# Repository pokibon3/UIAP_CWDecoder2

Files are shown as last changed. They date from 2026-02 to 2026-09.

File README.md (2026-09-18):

# CW Decoder for UIAPduino２

UIAPduino Pro Micro で動作する CW Decoder / FFT Analyzer です。  
VS Code + PlatformIO + `ch32v003fun` ベースでビルドできます。

このリポジトリでは、以下の 2 つのモードを切り替えて使えます。

- CW デコーダ
- FFT スペクトラムアナライザ

MODE SW を押すことでモード切り替えができます。

## 対応 MCU

- CH32V003(UIAPduino Pro Micro CH32V003 V1.4)
- CH32V006(UIAPduino Pro Micro CH32V006 V1.1)

`v1.7` 時点で、CH32V006 向けに以下を反映しています。

- LCD / GPIO 配線差分対応
- FLASH wait state 設定修正
- ADC 入力 `PA2 = ADC_IN0` 修正
- LED 制御を `PC3` に修正
- `ST7735` 向け `12x16` ANK フォント追加
- `ST7789` 向け `15x21` ANK フォント追加
- 006 では拡大描画ではなくネイティブ字形を使用

## 機能

### CW デコーダ

モールス信号を MIC 入力し、デコード結果を LCD に表示します。

- SW1: 英文 / 和文切り替え
- SW2: 600Hz / 700Hz / 800Hz / 900Hz / 1000Hz 切り替え（起動時 600Hz）

### FFT アナライザ

約 2.5kHz までのオーディオ信号スペクトルを表示します。  
ピーク周波数も表示します。

## ハード接続

### CH32V003 / CH32V006

| UIAP | CH32V003 / CH32V006 | 用途 |
|---|---|---|
| 10 | PD0 / PC0 | LCD DC |
| 8 | PC6 | LCD MOSI |
| 9 | PC7 | LCD RES |
| 7 | PC5 | LCD SCK |
| 5 | PC3 / PA4 | LCD CS |
| A1 | PA1 | SW1 |
| A2 | PC4 | SW2 |
| A3 | PD2 | SW3 |
| A0 | PA2 | MIC / ADC_IN0 |
| A6 | PD6 | TEST |
| LED | PC0 / PC3 | LED |

## ビルド

VS Code でこのフォルダを開き、PlatformIO IDE の機能を使ってビルドします。

1. VS Code でこのプロジェクトを開く
2. PlatformIO IDE が有効になっていることを確認する
3. 画面下部の PlatformIO ツールバーから `Build` を実行する

既定の environment は現在 `genericCH32V006F8U6` です。

## ファームウェア更新ツール

更新用パッケージは MCU と LCD 種別ごとに `tools` 配下へ整理しています。

- CH32V003 / ST7735: [tools/003/ST7735](tools/003/ST7735)
- CH32V003 / ST7789: [tools/003/ST7789](tools/003/ST7789)
- CH32V006 / ST7735: [tools/006/ST7735](tools/006/ST7735)
- CH32V006 / ST7789: [tools/006/ST7789](tools/006/ST7789)

今回の `v2.1` はデコード周波数の5段切り替え（600〜1000Hz）と、ノイズ混じり信号のデコード改善を行った版です。

- CH32V003 / ST7735 `v2.1` macOS: [tools/003/ST7735/mac/firmwareUpdate2.1](tools/003/ST7735/mac/firmwareUpdate2.1)
- CH32V003 / ST7735 `v2.1` Windows: [tools/003/ST7735/win/firmwareUpdate2.1](tools/003/ST7735/win/firmwareUpdate2.1)
- CH32V003 / ST7789 `v2.1` macOS: [tools/003/ST7789/mac/firmwareUpdate2.1](tools/003/ST7789/mac/firmwareUpdate2.1)
- CH32V003 / ST7789 `v2.1` Windows: [tools/003/ST7789/win/firmwareUpdate2.1](tools/003/ST7789/win/firmwareUpdate2.1)
- CH32V006 / ST7735 `v2.1` macOS: [tools/006/ST7735/mac/firmwareUpdate2.1](tools/006/ST7735/mac/firmwareUpdate2.1)
- CH32V006 / ST7735 `v2.1` Windows: [tools/006/ST7735/win/firmwareUpdate2.1](tools/006/ST7735/win/firmwareUpdate2.1)
- CH32V006 / ST7789 `v2.1` macOS: [tools/006/ST7789/mac/firmwareUpdate2.1](tools/006/ST7789/mac/firmwareUpdate2.1)
- CH32V006 / ST7789 `v2.1` Windows: [tools/006/ST7789/win/firmwareUpdate2.1](tools/006/ST7789/win/firmwareUpdate2.1)

`v2.0` 以前のパッケージも各ディレクトリの `firmwareUpdate2.0` などに残しています。

## 変更履歴

- V1.0
  - 新規リリース
- V1.1
  - オーディオ入力のダイナミックレンジ拡大
  - 欧文 / 和文切換えのバグ修正
  - モールスデコーダのデフォルト周波数を 600Hz に変更
  - FFT アナライザのスプラッシュ表示削除
- V1.2
  - DFT 周波数調整
  - 入力オーディオレベル調整
  - 周波数表示を 600Hz から 700Hz に変更
- V1.3
  - デコードタイミング微調整
  - デコード方式改善
- V1.4
  - 音声サンプリングのダブルバッファ化と表示期間の最適化
  - ノイズブランカの改善
  - LCD に 1.14inch ST7735/ST7789 をサポート
- V1.5
  - ST7735 / ST7789 ドライバを新規作成し最適化
  - 速度検出の安定化
  - ノイズによる誤動作の軽減
- V1.6
  - CH32V006 対応
  - GPIO / LCD 配線差分対応
  - FLASH wait state 設定修正
  - ADC 入力 `PA2 = ADC_IN0` 修正
  - ファームウェア更新ツールを `tools` 配下へ整理
- V1.7
  - CH32V006 の表示フォントを改善
  - ST7735 向け `12x16` ANK フォントを追加
  - ST7789 向け `15x21` ANK フォントを追加
  - 006 では拡大描画ではなくネイティブ字形を使用
  - 未認識符号を `*` で表示してバッファをリセットするよう修正
  - 符号バッファのオーバーフロー防止処理を追加
- V1.8
  - Goertzel を3ビン化（中心 + ±341.33Hz サイドビン、1パス処理。003 は整数 Q14、006 は float）
  - 中心/サイド比によるトーン判定を追加し、ホワイトノイズによる誤検出を抑制
  - サイドレベルは平滑化(EMA)後の min(low, high) を使用（片側混信に耐性）
  - 無信号からの立ち上がり時は瞬時サイドレベルも併用し、インパルス性ノイズ（QRN等）の誤検出を阻止
  - 速度推定を改良：長点も推定に利用して収束を高速化、低速側への変化率を制限してノイズバーストによる速度落ち込みを防止、WPM 表示は単位長から直接算出
  - 短点+長点ペア（比率1:3）検出による即時スナップを追加。20〜35wpm 帯ならノイズで倒れた速度推定がペア1組で瞬時に復帰（帯域外は緩やかに追従）
- V1.9
  - トーン判定にヒステリシス（シュミットトリガ）を導入。ON = 0.6×振幅しきい値かつ中心/サイド比3倍、OFF = 0.4×または2.5倍、中間は前状態保持。SNR 0dB でのデコード誤り 30〜43個/40秒 → 1〜2個（シミュレーション）
  - ギャップ（文字内1単位・文字間3単位）も速度推定の情報源に追加し、マーク+ギャップの1:3ペアでもスナップ。速度変化への追従を約2倍高速化（0.5〜0.7秒 → 0.1〜0.3秒）
- V2.0
  - サイド判定を min(low, high) から幾何平均 √(low×high) に変更。低域から通過帯域へ裾を引く傾斜ノイズ（バンドノイズ）が、静かな側のサイドとの比較をすり抜けて偽符号になる問題を抑止（ESP32 版 cw_decoder4 v2.0 で実機検証済みの対策を移植。003 整数版 / 006 float 版とも対応）
  - トーンON条件に「中心 > max(サイドEMA, サイド瞬時値)」を追加
- V2.1
  - デコード周波数を 600 / 700 / 800 / 900 / 1000Hz の5段切り替えに変更（SW2、起動時は 600Hz）
  - 従来 700 / 800Hz と表示していた設定は実際には 666.7 / 833.3Hz だったため、表示どおりの周波数に修正
  - ノイズ混じりの信号を音量を絞らずにデコードできるよう、振幅しきい値の床をノイズ床連動（×6）に変更し入力レベル非依存化。しきい値の追従は立ち上がり速く（1/6）、下降は遅く（1/64）
  - ノイズブランカを上下カウンタの積分方式に変更（深さ 0.35 単位、2〜3 ブロック）。しきい値付近のバタつきでギャップが埋まり短点が長点に融合する誤りを抑止（ESP32 版 cw_decoder4 v2.1/v2.2 の対策を移植）
  - スペアナ画面でスタックが溢れて FFT バッファを壊し、画面が出なくなることがある問題を修正

## 参考

製作方法や使い方は、以下も参照してください。  
[R16 Friendship Radio Scrapbox](https://scrapbox.io/r16fr/UIAPduino%E3%82%92%E4%BD%BF%E3%81%A3%E3%81%9FCW_Decoder%E3%81%AE%E8%A3%BD%E4%BD%9C)

## ライセンス

本ソフトのモールスデコーダ部分は、Hjalmar Skovholm Hansen OZ1JHM 氏の Arduino 用 CW Decoder を一部流用しています。  
オリジナルの GPL ライセンス条件が適用されます。

- Original: [http://oz1jhm.dk/content/very-simpel-cw-decoder-easy-build](http://oz1jhm.dk/content/very-simpel-cw-decoder-easy-build)
- GPL: [http://www.gnu.org/copyleft/gpl.html](http://www.gnu.org/copyleft/gpl.html)

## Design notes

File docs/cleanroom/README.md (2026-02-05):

# Clean-Room ST7789 Driver Plan

This folder defines the clean-room process and captures only specification-level
information. Do not place or copy any third-party source code here.

## Rules
- Do not read or reference existing ST7789 driver source code.
- Only use primary documents (datasheet, MCU reference, wiring).
- Record every assumption with a citation to a primary document.
- Keep implementation decisions separate from the spec.

## Files
- st7789_spec.md: Panel/MCU wiring, geometry, rotation, offsets, color order.
- st7789_init.csv: Initialization command list (sequence + delays).
- st7789_tests.md: Test plan for verification on hardware.

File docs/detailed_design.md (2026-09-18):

# CW Decoder for UIAP 詳細設計書（簡易版）

## 1. 概要
- 本ソフトは CH32V003 上で動作する CW 受信アプリ。
- 2つの動作モードを持つ。
  - CW Decoder Mode: モールス復号
  - Frequency Detector Mode: FFTによる周波数表示
- `SW1` で2モードを切り替える。

## 2. 全体構成
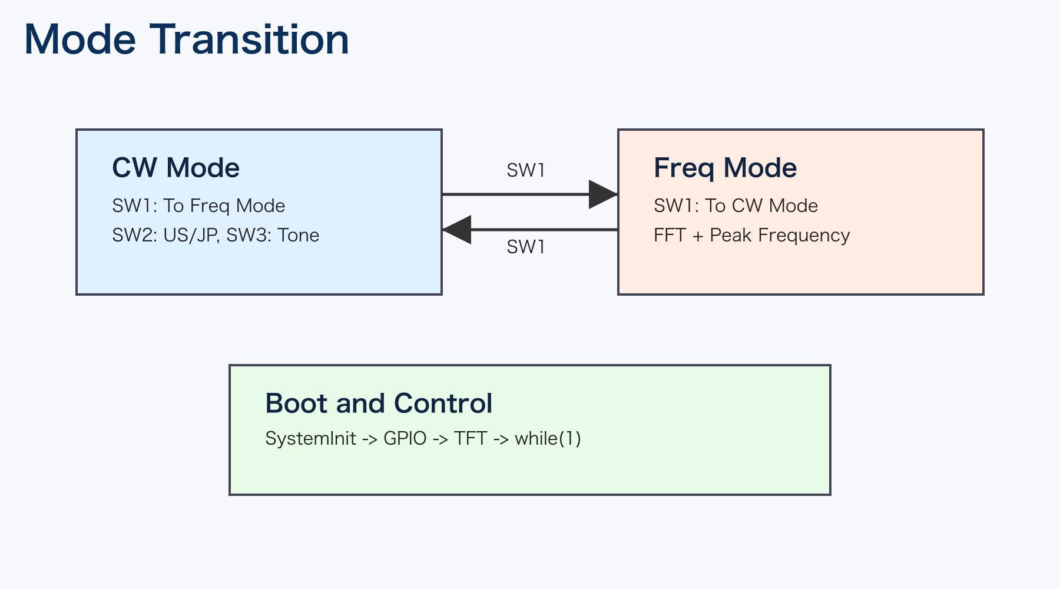
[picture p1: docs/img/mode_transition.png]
Mode Transition


構成要点:
- `main.cpp` がモード切替の主制御を行う。
- `common.cpp` が GPIO/ADC/タイマ/スイッチの共通処理を提供する。
- CW復号は Goertzel、周波数表示は FFT を使用する。
- 表示は TFT 抽象API経由で ST7735/ST7789 を切替可能。

## 3. モード遷移
- 起動後に初期化を行い、無限ループでモードを順に実行。
- CWモード中に `SW1` 押下で FFTモードへ。
- FFTモード中に `SW1` 押下で CWモードへ。

## 4. CW Decoder Mode
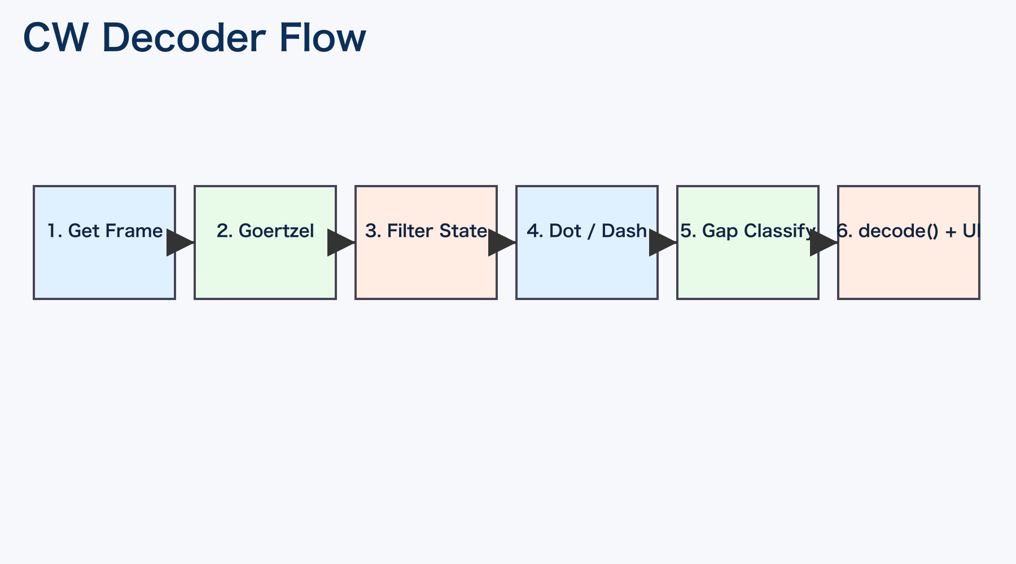
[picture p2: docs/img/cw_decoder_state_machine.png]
CW Decoder Flow


処理の流れ:
1. 音声サンプル取得
2. Goertzelで対象トーン成分を算出
3. しきい値とノイズ抑制でON/OFF状態を決定
4. ON時間から dot/dash 判定
5. OFF時間から文字間/単語間を判定
6. `decode.cpp` テーブルで文字変換し画面へ出力

操作:
- `SW2`: US/JP 切替
- `SW3`: トーン設定切替
- `SW1`: モード終了

## 5. Frequency Detector Mode
- ADCで 128 サンプル取得し FFT 実行。
- 最大ビンからピーク周波数を表示。
- スペクトラムバーを TFT に描画。
- `SW1` 押下でモード終了。

## 6. データとI/O
- 共有バッファ: `shared_buf[256]` を CW/FFT で共用。
- 主な入力:
  - 音声入力: PA2 (ADC)
  - SW1/2/3: PA1/PC4/PD2
- 主な出力:
  - TFT表示
  - LED表示 (CW状態)

## 7. ビルド設定
- `platformio.ini` でターゲットを管理。
- 既定は `TFT_ST7789`。
- 必要に応じて `TFT_ST7735` に切替可能。

## 8. 注意点
- グローバル変数を多用する構成のため、モジュールの独立性は高くない。
- タイミングは実機調整値に依存するため、クロック条件変更時は再調整が必要。

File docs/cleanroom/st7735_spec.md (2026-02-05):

# ST7735 Clean-Room Specification

## Source Documents
- ST7735 datasheet: [fill path or URL]
- CH32V003 reference: D:\src\cw_decoder3_for_uiap\docs\cleanroom\CH32V003.pdf
- Board wiring diagram: [fill path or URL]

## Target Hardware
- MCU: CH32V003
- Panel: ST7735, 80x160
- Interface: SPI 1-line TX
- Color format: 16-bit RGB565 (BGR order)
- Inversion: OFF

## Wiring (MCU -> ST7735)
- RESET: PC7
- DC: PD0
- CS: PC3 (optional if tied low)
- SCLK: PC5
- MOSI: PC6

## Geometry
- Display width: 160 px (landscape)
- Display height: 80 px (landscape)
- X offset: 0
- Y offset: 24

## Orientation
- Rotation: 0 degrees (landscape)
- MADCTL bits: MX=1, MY=0, MV=1, BGR=1
- MADCTL value: 0x68
- Rationale: [cite datasheet]

## Timing
- Reset pulse high/low: [ms]
- Sleep out delay: 120 ms
- Display on delay: 10 ms

## Command Set (minimum)
- SWRESET (0x01)
- SLPOUT (0x11)
- COLMOD (0x3A) = 0x05 (RGB565)
- MADCTL (0x36) = [bits above]
- INVOFF (0x20)
- DISPON (0x29)
- CASET (0x2A), RASET (0x2B), RAMWR (0x2C)
- VSCRDEF (0x33), VSCRSADD (0x37) [if scroll is required]

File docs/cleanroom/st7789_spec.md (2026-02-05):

# ST7789 Clean-Room Specification

## Source Documents
- ST7789 datasheet: D:\src\cw_decoder3_for_uiap\docs\cleanroom\ST7789.pdf
- CH32V003 reference: D:\src\cw_decoder3_for_uiap\docs\cleanroom\CH32V003.pdf
- Board wiring diagram: [fill path or URL]

## Target Hardware
- MCU: CH32V003
- Panel: ST7789, 1.14" 135x240
- Interface: SPI 1-line TX
- Color format: 16-bit RGB565
- Inversion: ON

## Wiring (MCU -> ST7789)
- RESET: PC7
- DC: PD0
- CS: PC3 (optional if tied low)
- SCLK: PC5
- MOSI: PC6

## Geometry
- Display width: 240 px (landscape)
- Display height: 135 px (landscape)
- X offset: 40
- Y offset: 53

## Orientation
- Rotation: 0 degrees
- MADCTL bits: MX=1, MY=0, MV=1, RGB=1, BGR=0
- MADCTL value: 0x60
- Rationale: [cite datasheet]

## Timing
- Reset pulse high/low: [ms]
- Sleep out delay: 120 ms
- Display on delay: 10 ms

## Command Set (minimum)
- SLPOUT (0x11)
- COLMOD (0x3A) = 0x55 (RGB565)
- MADCTL (0x36) = [bits above]
- INVON (0x21)
- DISPON (0x29)
- CASET (0x2A), RASET (0x2B), RAMWR (0x2C)
- VSCRDEF (0x33), VSCRSADD (0x37) [if scroll is required]

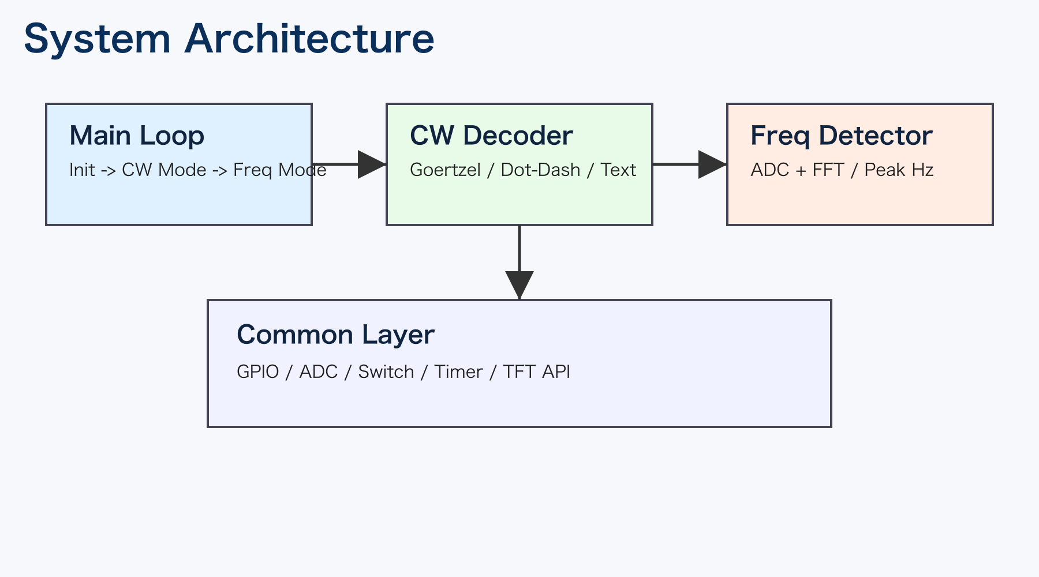
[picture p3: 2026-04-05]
docs/img/system_architecture.png

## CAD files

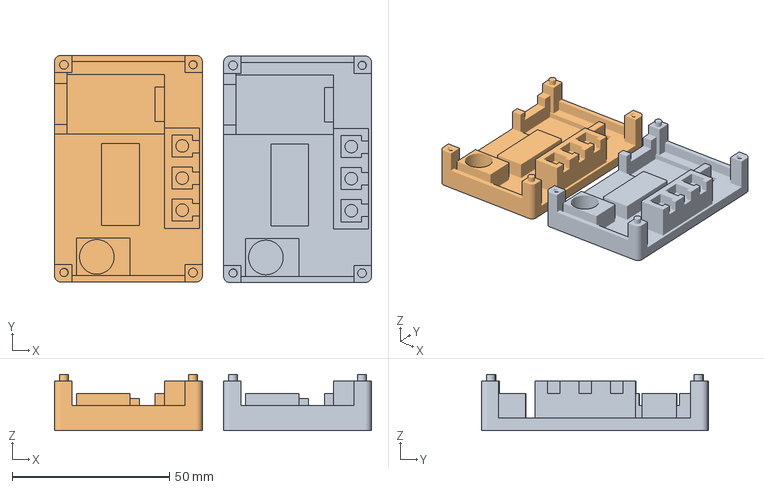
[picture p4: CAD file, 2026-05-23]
case/CW_DecoderSolderBase.3mf
100.7 x 72.2 x 17.8 mm
SOLDER_BASE2.stl x 2

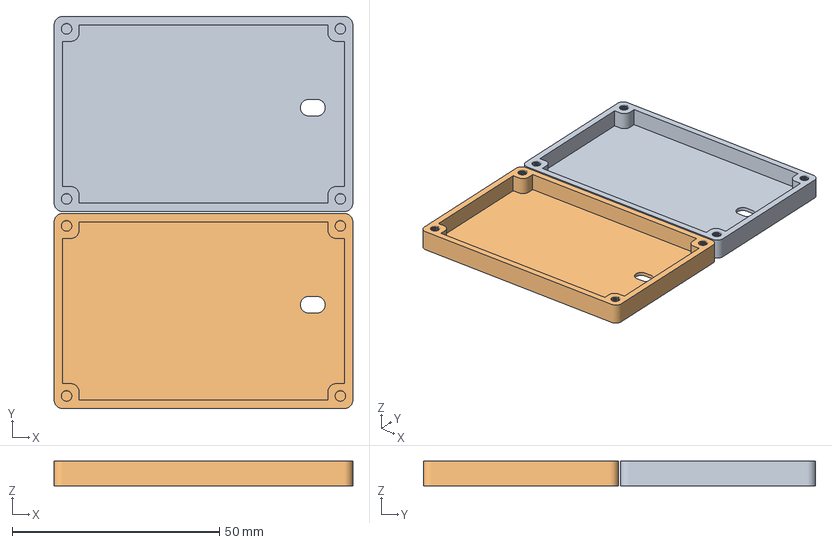
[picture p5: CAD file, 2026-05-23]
case/Bottom-2.3mf
72.0 x 94.5 x 6.00 mm
Bottom-2.stl x 2

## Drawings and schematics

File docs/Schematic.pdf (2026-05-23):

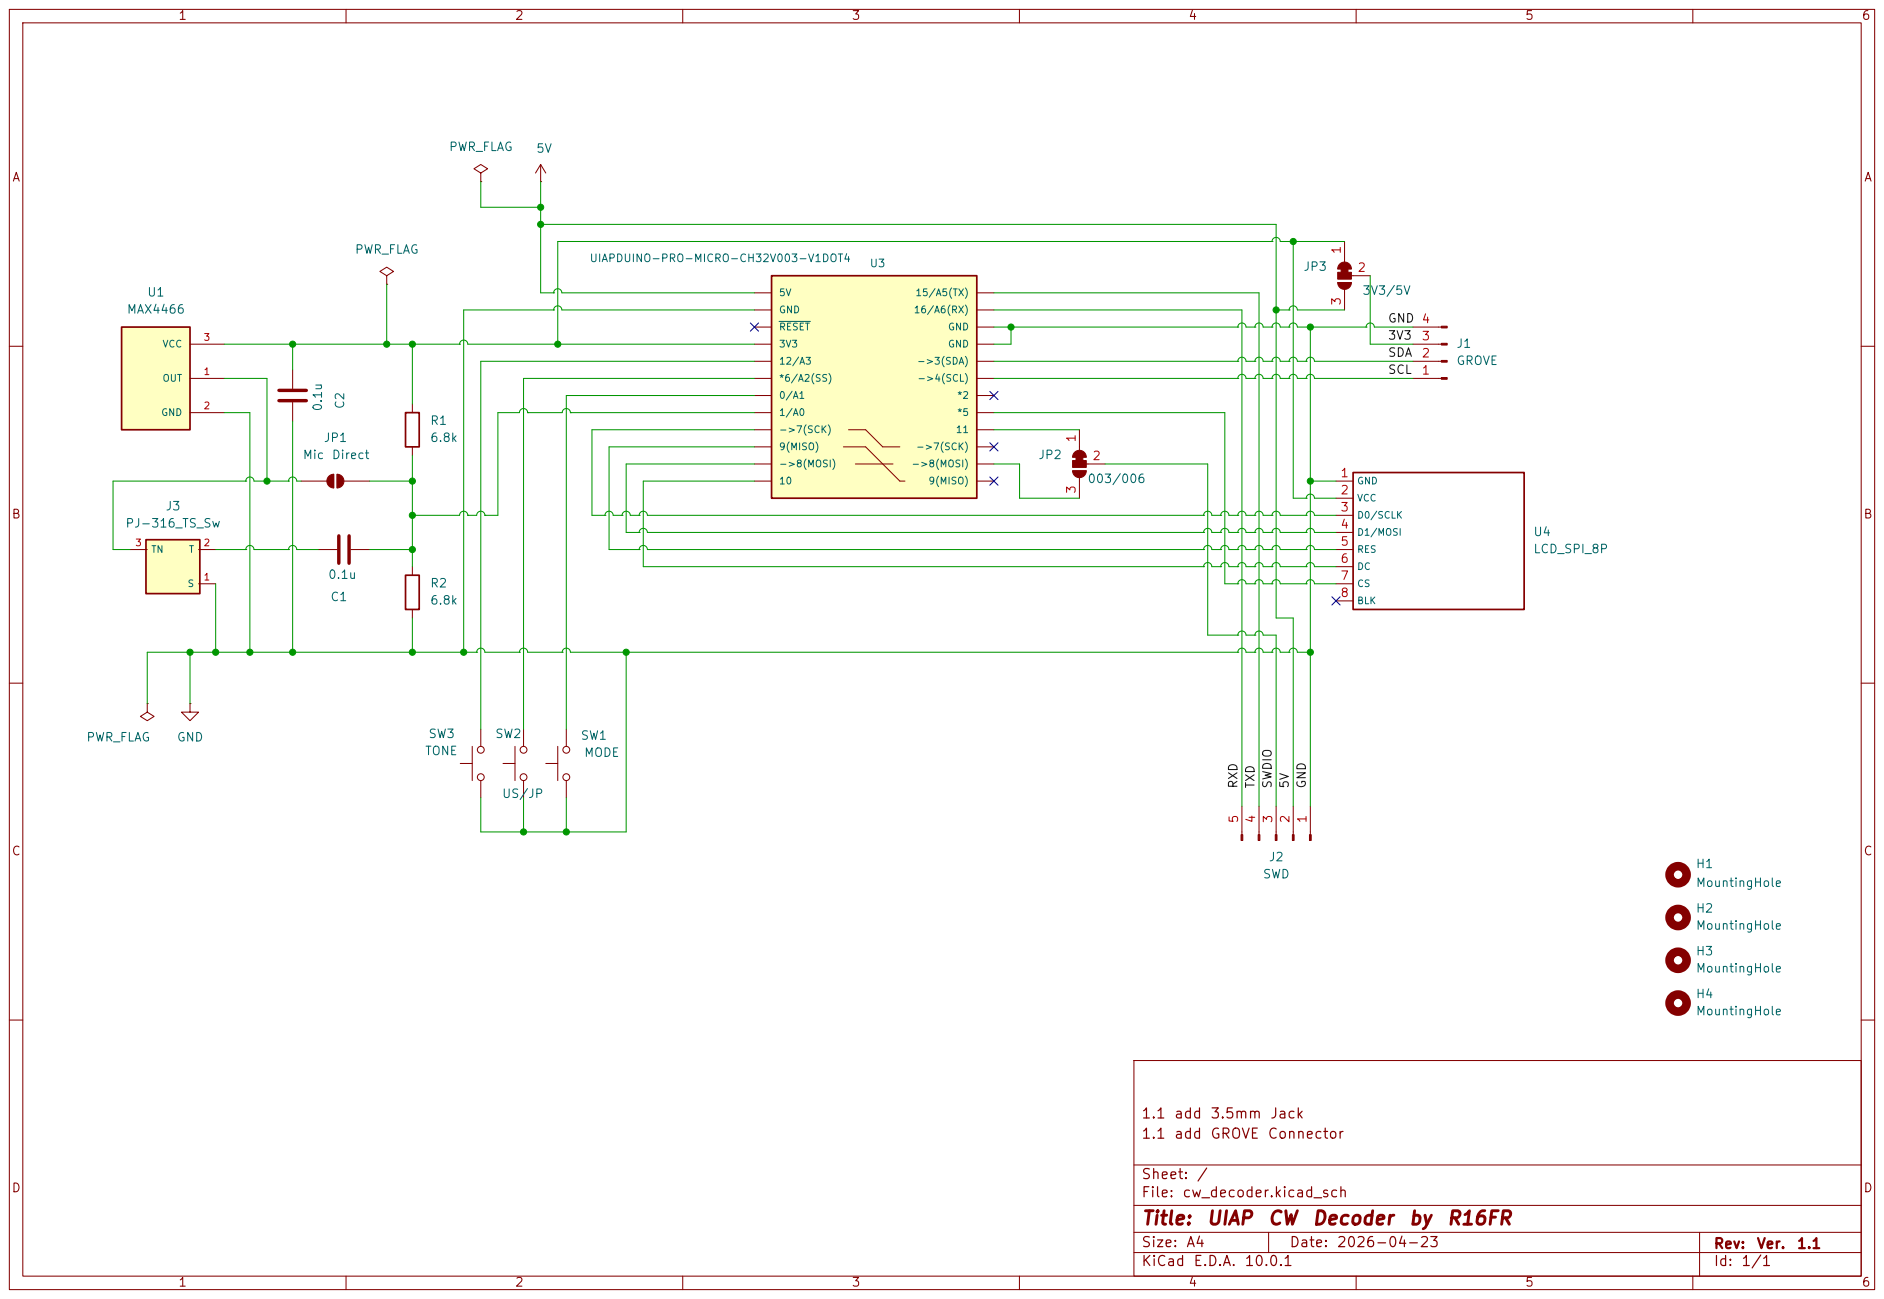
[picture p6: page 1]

Sheet: /
File: cw_decoder.kicad_sch
Title: UIAP CW Decoder by R16FR

Size: A4 | Rev: Ver. 1.1
KiCad E.D.A. 10.0.1 | Id: 1/1

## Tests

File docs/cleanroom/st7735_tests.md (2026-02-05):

# ST7735 Verification Tests

## Visual Tests
- Full-screen fill: black, white, red, green, blue
- 1px border rectangle at edges
- Crosshair through center
- Text grid with known coordinates

## Geometry Checks
- Verify top-left pixel maps to (0,0)
- Verify bottom-right pixel maps to (W-1,H-1)
- Adjust X/Y offsets if any clipping or overscan

## Color Order Checks
- RGB/BGR order test pattern
- Ensure no channel swapping (red/blue)

## Orientation Checks
- Verify 0/90/180/270 if rotation is supported

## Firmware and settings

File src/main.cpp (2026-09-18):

///////////////////////////////////////////////////////////////////////////
// CWデコーダ (Hjalmar Skovholm Hansen OZ1JHM) バージョン 1.01
// 自由に改変・複製できますが、GPL を遵守してください。
// ライセンス: <a href="http://www.gnu.org/copyleft/gpl.html"
// 		title="http://www.gnu.org/copyleft/gpl.html"
// 		rel="nofollow">http://www.gnu.org/copyleft/gpl.html</a>
// 議論・提案はこちら:
// <a href="https://groups.yahoo.com/neo/groups/oz1jhm/conversations/messages"
// 		title="https://groups.yahoo.com/neo/groups/oz1jhm/conversations/messages"
// 		rel="nofollow">https://groups.yahoo.com/neo/groups/oz1jhm/conversations/messages</a>
//
// KC2UEZ による改変 (バージョン 1.2):
// - Arduino NANO に対応
// - 起動時に「ターゲット周波数」と「帯域」を選択可能
///////////////////////////////////////////////////////////////////////////

///////////////////////////////////////////////////////////////////////////
// Goertzel 法の解説: <a href="http://en.wikipedia.org/wiki/Goertzel_algorithm" 
// 		title="http://en.wikipedia.org/wiki/Goertzel_algorithm"
// 		rel="nofollow">http://en.wikipedia.org/wiki/Goertzel_algorithm</a>
// FFT の参考: <a href="http://www.dspguide.com/pdfbook.htm"
// 		title="http://www.dspguide.com/pdfbook.htm"
// 		rel="nofollow">http://www.dspguide.com/pdfbook.htm</a>
///////////////////////////////////////////////////////////////////////////

///////////////////////////////////////////////////////////////////////////
//
//	CW Decoder Ver for UIAPduino Pro Micro
//
// 改変版 (Kimiwo Ohe)
// 変更点:
//  - UIAPduino Pro Micro(CH32V003) に移植
//  - 周波数検出機能を追加
//  - 全ソースをリファクタリング
// 日付: 2025-11-07 バージョン 1.0
//  - DFT を Goertzel 法に変更
// 日付: 2025.12.05 バージョン 1.1
//  - オーディオ入力ダイナミックレンジ拡大
// 日付: 2025.12.13 バージョン 1.2
//  - DFTの周波数を調整
//  - DFTの入力レベルを調整
// 日付: 2025.12.20 バージョン 1.3
//  - デコードタイミング微調整
// 日付: 2026.02.04 バージョン 1.4
//  - LCDに1.14inch ST7739をサポート
//　- 音声サンプリングのダブルバッファ化と表示期間の最適化
//  - ノイズブランカの改善
// 日付: 2026.02.07 バージョン 1.5
//  - ST7735/7789のドライバを新規作成し最適化
//  - 速度検出の安定化
//  - ノイズによる誤動作の軽減
// 日付: 2026.04.07 バージョン 1.6
//  - CH32V006 対応
//  - LCD/GPIO 配線差分に対応
//  - FLASH wait state 設定の修正
//  - ADC入力 PA2 を ADC_IN0 として修正
//  - CH32V006 の LED 制御を PC3 に修正
// 日付: 2026.04.10 バージョン 1.7
//  - CH32V006 の表示フォントを改善
//  - ST7735 は 12x16 ANK フォントを追加
//  - ST7789 は 15x21 ANK フォントを追加
//  - 2倍/3倍の単純拡大をやめ、006ではネイティブ字形を使用
// 日付: 2026.07.12 バージョン 1.8
//  - Goertzel を3ビン化 (中心 + ±341.33Hz サイドビン、003は整数Q14/006はfloat)
//  - 中心/サイド比によるトーン判定でホワイトノイズを棄却
//  - 立ち上がり時は瞬時サイドも併用しインパルスノイズを棄却
//  - 速度推定を改良 (長点も利用して高速収束、低速側への変化率制限)
//  - 短点+長点ペア検出で20〜35wpm帯へ即時スナップ復帰
// 日付: 2026.07.12 バージョン 1.9
//  - トーン判定にヒステリシス導入 (ON 0.6x/3x, OFF 0.4x/2.5x)
//    SNR 0dB でのデコード誤りをほぼ解消
//  - ギャップ(文字内/文字間)も速度推定に利用し、速度変化追従を約2倍高速化
// 日付: 2026.07.20 バージョン 2.0
//  - サイド判定を min(L,H) から幾何平均 sqrt(L*H) に変更
//    低域から通過帯域へ裾を引く傾斜ノイズ(バンドノイズ)による偽符号を抑止
//  - トーンONに「中心 > max(サイドEMA, サイド瞬時)」条件を追加
//    (ESP32版 cw_decoder4 v2.0 で実機検証済みの対策を移植)
// 日付: 2026.09.18 バージョン 2.1
//  - デコード周波数を 600/700/800/900/1000Hz の5段切替に変更 (デフォルト 600Hz)
//    従来の 700/800 表示は実際には 666.7/833.3Hz だったのを表示どおりの周波数に修正
//  - 振幅しきい値の床をノイズ床連動 (x6) に変更し、入力レベル非依存化
//    (ノイズ混じりの信号を音量を絞らずにデコードできるように)
//  - しきい値の追従を立ち上がり速く(1/6)/下降遅く(1/64)に
//  - ノイズブランカを上下カウンタの積分方式に変更 (深さ 0.35 単位、2〜3 ブロック)
//    (ESP32版 cw_decoder4 v2.1/v2.2 の対策を移植)
//  - スペアナ画面のスタック溢れ (FFT バッファ破壊) を修正
//
// このソフトウェアは GNU General Public License (GPL) に基づき配布されています。
// 改変版も同じ GPL ライセンスで再配布してください。
///////////////////////////////////////////////////////////////////////////
//
//  Hardware Connections
//
//	UIAP	CH32V003/006  	TFT(SPI)	SW		MIC    	 ETC.
//	10	    PD0 / PC0       DC
//	 8      PC6            MOSI
//   9      PC7            RES
//   7      PC5            SCK
//   5      PC3 / PA4      CS
//	A1	    PA1                         SW1
//	A2      PC4                         SW2
//  A3      PD2							SW3
//	A0		PA2									OUT(ADC_IN0)
//  A6		PD6                                 TEST
//  LED     PC0 / PC3
//	3.3V                  3.3V           		VCC(Via 78L33 3.3V)
//  GND                    GND          		GND
//
///////////////////////////////////////////////////////////////////////////

#include <stdio.h>
#include <stdlib.h>
#include <string.h>

#include "common.h"
#include "ch32fun.h"
#include "cw_decoder.h"
#include "frequencyDetector.h"

uint16_t sampling_period_us;
alignas(2) uint8_t  shared_buf[BUFSIZE];

#if defined(BOARD_CH32V006)
alignas(4) float fft_real[SAMPLES];
alignas(4) float fft_imag[SAMPLES];
#endif

//==================================================================
//	main
//==================================================================
int main()
{
	SystemInit();				// MCU setup
	GPIO_setup();				// GPIO/ADC setup
    tft_init();					// LCD init

#if !defined(BOARD_CH32V006)
	int8_t *vReal;
	int8_t *vImag;
	vReal = (int8_t *)&shared_buf[0];
	vImag = (int8_t *)&shared_buf[128];
#endif
	while (1) {
		// cw decoder
		cwd_setup();			// freq detector Setup
		cwDecoder();			// run cw decoder
		// frequency detector
		fd_setup();				// freq detector Setup
#if defined(BOARD_CH32V006)
		freqDetector(fft_real, fft_imag);			// run freq counter
#else
		freqDetector(vReal, vImag);			// run freq counter
#endif
	}
	return 0;
}

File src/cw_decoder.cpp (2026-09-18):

//
//	CWデコーダ関数
//
#include <stdio.h>
#include <stdlib.h>
#include "common.h"
#include "goertzel.h"
#include "decode.h"
#include "ch32fun.h"
#include "cw_display.h"

//#define SERIAL_OUT

#define GOERTZEL_SAMPLES 48
#define GOERTZEL_SAMPLING_FREQUENCY 8192
#define NOISE_BLANKER_ENABLED 1
// トーン判定: 中心ビンがサイドレベル(±341.33Hzビンの平滑化後min)の
// 何倍あれば正弦波とみなすか。ホワイトノイズは全ビンほぼ同レベル、
// 正弦波は10倍以上になる。サイドは幾何平均√(L×H)を使用 (v2.0):
// min(L,H)だと低域から裾を引く傾斜ノイズが静かな側との比較をすり抜ける。
#define TONE_SIDE_RATIO 3
// トーン判定のヒステリシス(シュミットトリガ):
// ON  = 振幅 0.6×limit 超 かつ 中心 > 3×サイド
// OFF = 振幅 0.4×limit 未満 または 中心 < 2.5×サイド
// 中間帯は前状態を保持し、しきい値付近のバタつきでマークが千切れるのを防ぐ。
// (OFF をこれ以上緩めるとホワイトノイズの保持が伸びて誤記号が出る)
#define TONE_SIDE_RATIO_OFF_X10 25
// 実運用の中心速度帯 20〜35wpm の単位長範囲 (ms、マージン込み)。
// 短点+長点ペアで求めた単位長がこの範囲なら速度推定を即時スナップする。
#define WPM_CORE_UNIT_MIN 30
#define WPM_CORE_UNIT_MAX 66
static int32_t magnitudelimit = 140;
static int32_t magnitudelimit_low = 140;
// 振幅しきい値 (magnitudelimit) の追従 (v2.1): 立ち上がりは速く (1/6 = τ35ms)、
// 下降は遅く (1/64 = τ0.38s) してピークホールド的に振る舞わせる。
// 旧来の対称 1/6 では文字間ギャップで limit がノイズ床まで崩落して振幅条件が
// 無効化され、絶対床 140 が「入力を極端に絞ったときだけ」スケルチとして
// 働いていた (ノイズ混じりは音量をかなり下げないとデコードできなかった)。
#define LIMIT_ATTACK_DIV 6
#define LIMIT_DECAY_DIV 64
// ノイズ床に連動した相対スケルチ (v2.1): トーンらしくないブロックの中心
// マグニチュードを遅い EMA (1/128 = τ0.75s) で追い、limit の床を
// noise_floor x 6 にする (ON 下限 = 0.6 x 床 = ノイズ平均 x 3.6)。
// EMA は Q8 で蓄積する (整数 EMA は小さな差で動かず片道ラチェットになる)。
// (ESP32版 cw_decoder4 v2.1/v2.2 の対策を移植。同版は実機ログで x8 に
//  上げているが、窓条件が異なるため x6 から調整する)
static int32_t noise_floor = 0;
static int32_t noise_acc = 0;       // noise_floor の Q8 蓄積値
#define NOISE_FLOOR_DIV 128
#define NOISE_SQUELCH_X10 60
static uint16_t realstate = GPIO_LOW;
static uint16_t realstatebefore = GPIO_LOW;
static uint16_t filteredstate = GPIO_LOW;
static uint16_t filteredstatebefore = GPIO_LOW;
static uint32_t starttimehigh;
static uint32_t highduration;
static uint32_t lasthighduration;
static uint32_t hightimesavg = 60;
static uint32_t startttimelow;
static uint32_t lowduration;
// ノイズブランカの積分値 (0..深さ)
static uint8_t nb_acc = 0;
// 1ブロック = 48/8192Hz = 5.86ms。深さは 0.35 単位ぶんのブロック数 (四捨五入)
// = unit[ms] x 0.35 / 5.86 ≒ unit x 6 / 100。上限 3 ブロック (17.6ms) は
// 推定が遅い側へ外れても 50WPM の短点 (24ms) を残すための保険
#define NB_DEPTH_MIN 2
#define NB_DEPTH_MAX 3

static char code[20];
static uint16_t stop = GPIO_LOW;
static uint16_t wpm;
static uint32_t last_mark_ms = 0;
static uint32_t last_gap_ms = 0;

static char		sw = MODE_US;
static int16_t 	speed = 0;

uint8_t lastChar = 0;

extern uint8_t shared_buf[BUFSIZE];
static volatile uint32_t morseSum[2];
static volatile uint16_t morseWriteIndex = 0;
static volatile uint8_t morseWriteBuf = 0;
static volatile uint8_t morseReady[2] = { 0, 0 };

static inline int16_t *get_morse_buf(uint8_t idx)
{
	return (int16_t *)shared_buf + (idx * GOERTZEL_SAMPLES);
}

static void reset_morse_buffers(void)
{
	morseSum[0] = 0;
	morseSum[1] = 0;
	morseWriteIndex = 0;
	morseWriteBuf = 0;
	morseReady[0] = 0;
	morseReady[1] = 0;
}

static void push_morse_sample(uint16_t sample)
{
	if (morseReady[morseWriteBuf]) {
		uint8_t next = morseWriteBuf ^ 1;
		if (!morseReady[next]) {
			morseWriteBuf = next;
			morseWriteIndex = 0;
			morseSum[morseWriteBuf] = 0;
		} else {
			return;
		}
	}

	if (morseWriteIndex >= GOERTZEL_SAMPLES) {
		morseWriteIndex = 0;
		morseSum[morseWriteBuf] = 0;
	}

	get_morse_buf(morseWriteBuf)[morseWriteIndex] = (int16_t)sample;
	morseSum[morseWriteBuf] += sample;
	morseWriteIndex++;
	if (morseWriteIndex >= GOERTZEL_SAMPLES) {
		morseReady[morseWriteBuf] = 1;
		uint8_t next = morseWriteBuf ^ 1;
		if (!morseReady[next]) {
			morseWriteBuf = next;
			morseWriteIndex = 0;
			morseSum[morseWriteBuf] = 0;
		} else {
			morseWriteIndex = GOERTZEL_SAMPLES;
		}
	}
}

static inline int32_t normalize_decoder_magnitude(int32_t magnitude)
{
#if defined(BOARD_CH32V006)
	return magnitude >> 2;
#else
	return magnitude;
#endif
}

extern "C" void TIM1_UP_IRQHandler(void) __attribute__((interrupt));
extern "C" void TIM1_UP_IRQHandler(void)
{
	if (TIM1->INTFR & TIM_IT_Update) {
		TIM1->INTFR = (uint16_t)~TIM_IT_Update;
	}

	push_morse_sample((uint16_t)(adc_read_raw() >> 1));
}

//==================================================================
// gap を 1単位 hightimesavg の相対値で分類
//==================================================================
typedef enum {
	GAP_INTRA = 0, // 文字内
	GAP_CHAR  = 1, // 文字間
	GAP_WORD  = 2  // 単語間
} gap_type_t;

static gap_type_t classify_gap(uint32_t gap, uint32_t unit)
{
	if (unit == 0) return GAP_INTRA; // まだ学習前の保護

	// gap < 1.5 * unit → 同一文字内
	if (gap < (unit * 3) / 2) {
		return GAP_INTRA;
	}
	// 1.5〜4.5 * unit → 文字間
	if (gap < (unit * 9) / 2) {
		return GAP_CHAR;
	}
	// 6 * unit 以上 → 単語間
	if (gap >= unit * 6) {
		return GAP_WORD;
	}

	// 4.5〜6 * unit は微妙ゾーン → とりあえず文字間に寄せる
	return GAP_CHAR;
}

//==================================================================
//	単位長(短点)の推定ヘルパー
//==================================================================
// 比率~1:3のペア(短点+長点、または短点+文字間ギャップ等)から単位長候補を
// 求める。20〜35wpm帯のみ有効。同じ長さのペアは「短点2つ」とも「長点2つ」
// とも解釈できて曖昧なため使わない(低速CWを壊さないための安全条件)。
static uint32_t snap_candidate(uint32_t a, uint32_t b)
{
	uint32_t hi = (a > b) ? a : b;
	uint32_t lo = (a > b) ? b : a;
	if ((hi * 10) >= (lo * 24) && (hi * 10) <= (lo * 36)) {
		uint32_t cu = (lo + hi / 3) / 2;
		if (cu >= WPM_CORE_UNIT_MIN && cu <= WPM_CORE_UNIT_MAX) {
			return cu;
		}
	}
	return 0;
}

static void unit_clamp(void)
{
	if (hightimesavg < 24) {
		hightimesavg = 24;
	}
	if (hightimesavg > 300) {
		hightimesavg = 300;
	}
}

// スナップ: 現在値から大きくズレていれば即時復帰、近ければ平滑化
static void unit_apply_snap(uint32_t snap)
{
	uint32_t diff = (snap > hightimesavg) ? (snap - hightimesavg)
	                                      : (hightimesavg - snap);
	if (diff * 4 > hightimesavg) {
		hightimesavg = snap;
	} else if (snap >= hightimesavg) {
		hightimesavg += (snap - hightimesavg) / 3;
	} else {
		hightimesavg -= (hightimesavg - snap) / 3;
	}
	unit_clamp();
}

// 緩やか追従: 2単位未満は1単位(そのまま)、以上は3単位(1/3)として反映。
// 低速側の推定値は現在値の2倍でクリップし、持続ノイズバーストで
// 一気に低速側へ倒れないよう変化率を制限する。
static void unit_smooth_update(uint32_t dur)
{
	uint32_t est = dur;
	if (dur >= (2 * hightimesavg) && hightimesavg != 0) {
		est = dur / 3;
		if (est > hightimesavg * 2) {
			est = hightimesavg * 2;
		}
	}
	if (est >= hightimesavg) {
		hightimesavg += (est - hightimesavg) / 3;
	} else {
		hightimesavg -= (hightimesavg - est) / 3;
	}
	unit_clamp();
}
//==================================================================
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

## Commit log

2026-01-26 Split display module and tweak noise blanker
    [cw_decoder.cpp]
2026-01-26 Queue display output and revert ST7789 scroll
    [cw_decoder.cpp]
2026-02-05 Update TFT drivers and config
2026-02-05 Remove st7789_legacy driver
2026-02-05 Replace ST7789 driver and add clean-room spec
    [st7789_init.csv]
2026-02-05 Tighten font metrics and title layout
    [main.cpp]
2026-02-05 Clean ST7735 driver and add specs
    [st7735_init.csv]
2026-02-05 DMA scanline FFT rendering
2026-02-07 Tune CW decoding stability and update display highlighting/colors
    [cw_decoder.cpp]
2026-02-08 Switch to community ch32v003fun and refactor GPIO/ADC access
2026-02-08 Add BK prosign and switch ADC read to direct register access
2026-02-08 Improve FFT frequency display stability with 1s hold
    [frequencyDetector.cpp]
2026-04-05 Add CH32V006 support with float FFT and peak hold display
    - Add genericCH32V006F8U6 target to platformio.ini (default env)
    - Add BOARD_CH32V006 #ifdef separation (no ch32v003_GPIO_branchless.h)
    - Add float FFT library (lib/float_fft/) for V006; keep integer FFT for V003
    - Replace isqrt32() with sqrtf() on V006 path
    - Apply UIAPduino CN3/CN4 pin assignments for V006 (LED=PC3, ADC ch2)
    - Add peak hold display (CYAN line, 20-frame hold) for both chips
    - Add V006 TIM1 compat defines in funconfig.h
    - Use adc_read_raw() for V006 ADC (ADC_CH_A2=2 for PA2)
    - V006: RAM 31.9% / Flash 35.7% V003: RAM 65.8% / Flash 76.4%
    [common.cpp, frequencyDetector.cpp, main.cpp]
2026-04-05 Revert code changes to v1.5 baseline
    [common.cpp, frequencyDetector.cpp, main.cpp]
2026-04-06 WIP CH32V006 ADC trigger and FFT path investigation
2026-04-06 Finalize CH32V006 ADC channel and LCD support
2026-04-06 Remove unnecessary ADC settle delay
2026-04-07 Enable CH32V006 LED and float Goertzel
2026-04-07 Finalize v1.6 CH32V006 ADC and FFT updates
2026-04-08 Adjust mac firmwareUpdate1.6 flash VID/PID
2026-05-23 add gerber and schematic
2026-05-23 Add case folder
    [Bottom-2.3mf, CW_DecoderSolderBase.3mf]
2026-05-23 Add assembly guide PDFs
2026-05-25 Fix code buffer overflow and display * for unrecognized CW symbols (v1.6a)
    - Add decode_and_display() helper that shows '*' when no CW match found
    - Guard strcat with strlen >= 8 check to prevent buffer overflow
    - Update version string to v1.6a
    [cw_decoder.cpp]
2026-05-25 Fix forward declaration of decodeAscii for decode_and_display
    [cw_decoder.cpp]
2026-07-11 Port v1.8 tone discrimination and speed estimation from cw_decoder4
    3-bin Goertzel (center + sides at exactly +-2 DFT bins = +-341.33 Hz,
    on Dirichlet-kernel nulls) computed in one pass:
    - CH32V003: new integer implementation, Q14 coefficients with shifts
    (faster and more precise than the old coeff100 multiply/divide);
    0.70 ms per 48-sample block measured on rv32ec, 12% of the 5.86 ms
    budget. Flash fits at 81.5% of 16 KB.
    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
2026-07-19 Reject sloped band noise in the tone gate (v2.0)
    Port the noise rejection verified on the ESP32 port (cw_decoder4 v2.0):
    - Side level for the center/side ratio test is now the geometric mean
    sqrt(L*H) of the per-side EMAs instead of min(L, H). Sloped band noise
    reaching into the passband raised only the low side, so min() compared
    the center against the quiet high side and let noise spikes through as
    false marks. With a real tone both sides are quiet and the geometric
    mean equals min(), so sensitivity is unchanged
    - tone_on additionally requires the center to exceed the max of both
    side EMAs and both instantaneous side magnitudes
    - CH32V003 integer version computes the geometric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
    [cw_decoder.cpp, main.cpp]
2026-09-18 Switch decode tone to 5 steps 600-1000 Hz (v2.1)
    - SW2 now cycles 600 / 700 / 800 / 900 / 1000 Hz (was 3 steps).
    Default at power-on is 600 Hz
    - The old "700" / "800" settings actually ran at 666.7 / 833.3 Hz
    (legacy fs=8000 bin centers); coefficients are now computed for the
    displayed frequencies at fs=8192, sides stay at +-341.33 Hz
    - Tone count is shared via GOERTZEL_TONES in goertzel.h
    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
2026-09-18 Level-independent tone threshold and integrating noise blanker (v2.1)
    Noisy signals only decoded with the input turned well down: the tone
    limit tracked symmetrically (1/6), so it collapsed to the noise level in
    every keying gap, and the fixed floor 140 only acted as a squelch when
    the noise was below it. Ported from cw_decoder4 v2.1/v2.2:
    - Track a noise floor (Q8 EMA, 1/128 = tau 0.75s) from blocks that are
    not tone-like or below the floor, and clamp the limit at 6x it
    - Limit attacks fast (1/6) and decays slowly (1/64)
    - Replace the "stable for nbtime" blanker, whose timer reset on every
    flicker, with an up/down counter 0.35 unit deep (2-3 blocks); both
    edges are delayed equally, s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
    [cw_decoder.cpp, frequencyDetector.cpp, main.cpp]
2026-09-24 Follow the intra-character spacing instead of a fixed 1.5 units (v2.2)
    符号内スペースが短点より長い送信でデコードが全崩れする問題を修正した。
    ESP32 版 cw_decoder4 v3.2 の対策を移植。classify_gap() は両版で同一だった
    ので、同じバグが同じ形で存在していた。
    実測 (POTA QSO 録音): 短点 51ms / 長点 165ms に対し符号内スペースが 83ms
    あり、短点の 1.63 倍。長点比 3.24、語間 6.8 短点はどちらも標準的で、
    崩れているのは符号内スペースだけだった。固定の「1.5 単位以上は文字間」で
    切ると、マーク由来の単位長 51ms に対し境界が 76ms となり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
2026-10-31 Suppress stray E/T on noise and keep the noise blanker from bridging gaps (v2.3)
    ESP32 版 cw_decoder4 の 2 つの対策を移植した。
    1. ノイズだけの区間の E/T 抑止 (cw_decoder4 7494f8b)
    直近 12 文字のうち 1 要素の文字が 9 個以上を占めるあいだ、1 要素の文字を
    捨てる。抑止した分も履歴に数えるので、ノイズが止まれば自然に復帰する。
    1 文字ごとの特徴では本物と区別できず、効くのは文脈だけ (本物の CW の
    E/T は 19〜43%、ノイズだけの区間では 69〜71%)。
    2. ノイズブランカの隙間保持 (cw_decoder4 90ce9e0)
    HIGH から下がりかけている途中に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
2026-10-31 Docs: add release dates and condense the changelog
    変更履歴の各版にリリース日を付け、説明を短い体言止めにそろえた。実測値などの
    細かい数字は省き、技術用語で書き直した。日付は src/main.cpp の改版履歴
    (v1.0〜v2.1) と各版のコミット日 (v2.2、v2.3) による。
